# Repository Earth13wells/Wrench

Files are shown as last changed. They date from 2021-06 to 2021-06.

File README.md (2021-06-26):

# Wrench

Print in place, 3D printable ratchet wrench!    

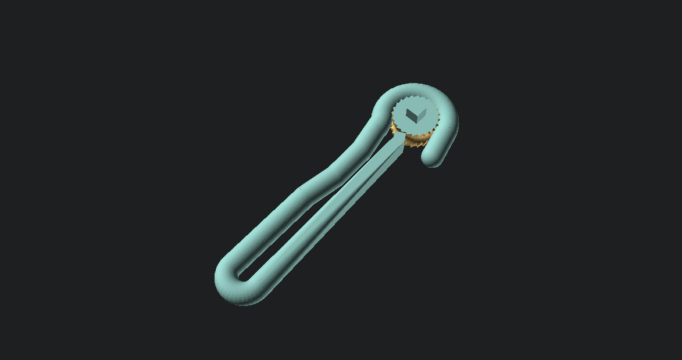
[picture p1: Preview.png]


### Currently Compiling With:
  - OpenScad

### Specs:
  - 1/4" (0.635cm) Drive
  - 3.9" (10 cm) Handle
  - 24 tooth ratchet

### Reasoning:
  - Inspired by the Nasa Space wrench
  - Was a good reason to play with tolerances in openscad

### Suggested Print Settings: (tested V2)
  - Wrench.stl 15-35% infill with 2 permitter+ (tested at 20%,2p)
  - ratchetPaul.stl 30-100% infill with 3 permitter+ (tested at 35%,4p)

## Testing V1:
Using the testing method pictured:         
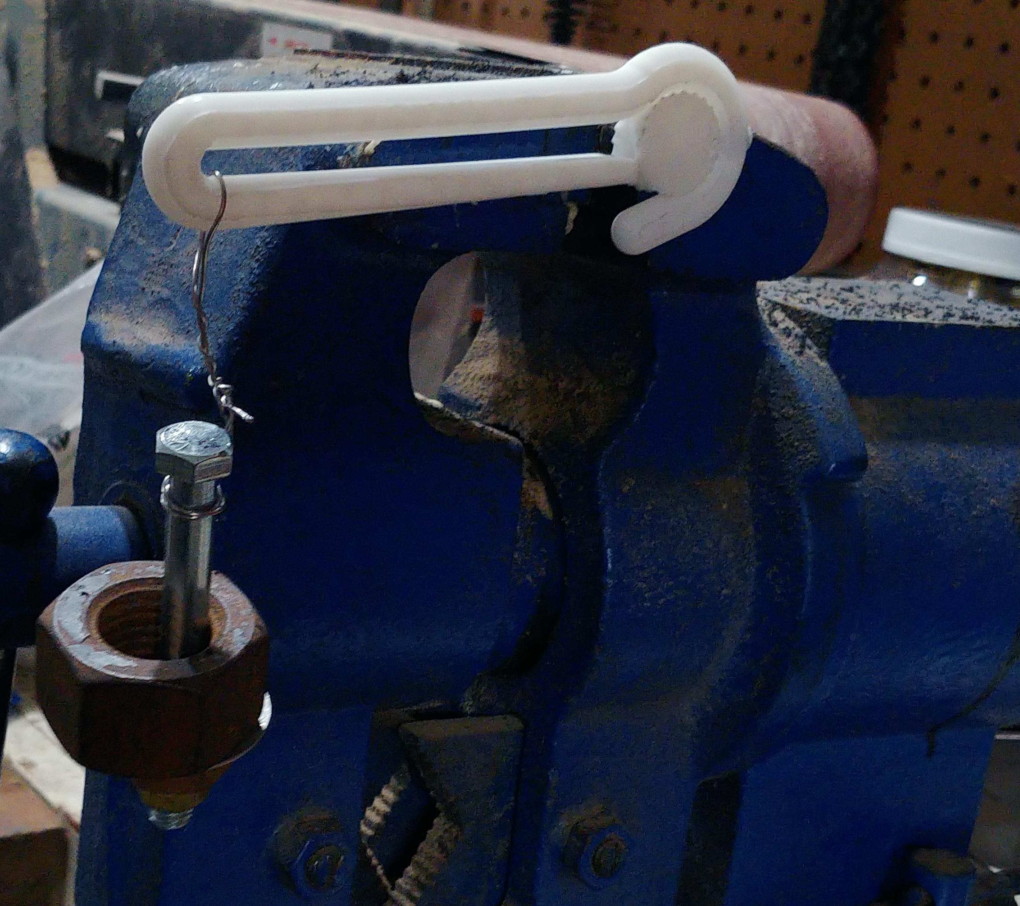
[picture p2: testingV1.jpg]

(weights shown not accurate to final result)         
The wrench was found to support 1.749kg ± .060kg,         
when the mass was suspended 105mm ± 1mm from the centre of the 1/4" drive.         
Using the formula ma/l = τ the force required to break the wrench is:         
```bash
(1.749kg * 9.801N/kg)
 (105mm * 0.001mm/m)   = 1.80N/m (τ)
```
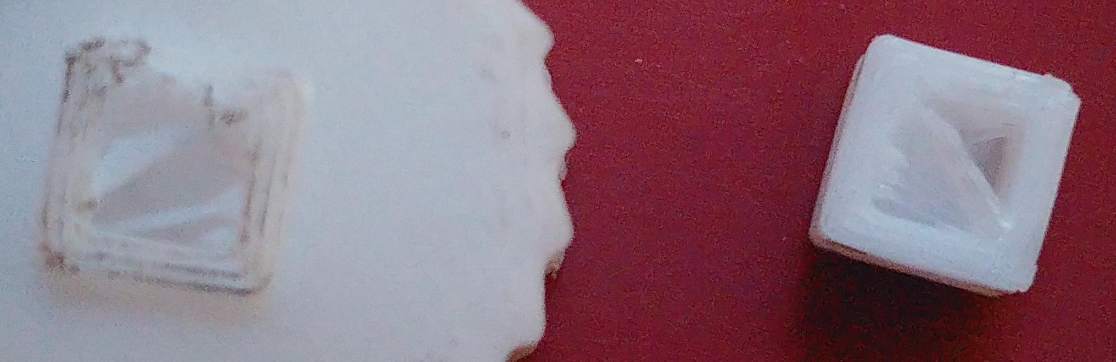
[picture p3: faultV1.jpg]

the fault shown is exactly what was expected, yet not corrected in the design.         
the solution going forward is to print the handle and ratchet separately,         
as the infill/permitter count can be increased on the weaker parts         
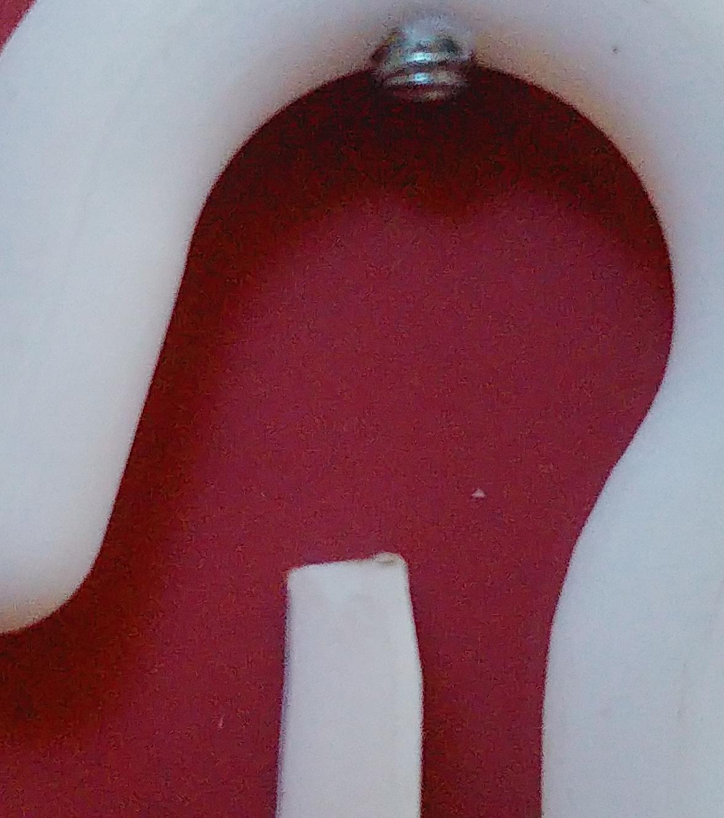
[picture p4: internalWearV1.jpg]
         
The lack of wear on the internals is a very welcome sight, as this part will not need to be redesigned.         
The lever arm is also in excellent condition         
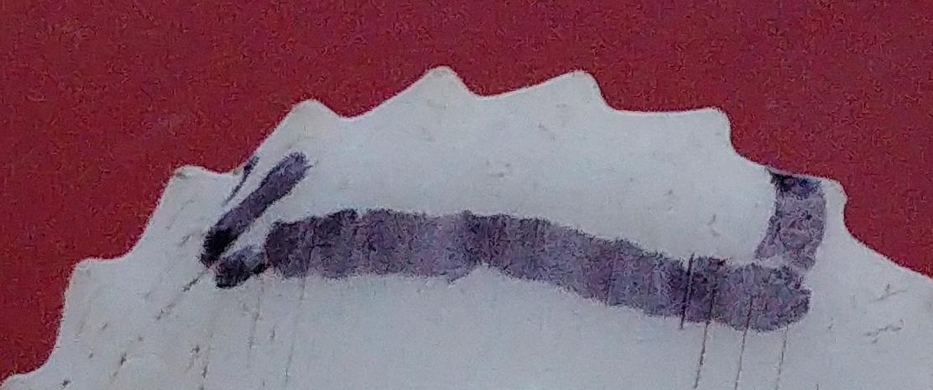
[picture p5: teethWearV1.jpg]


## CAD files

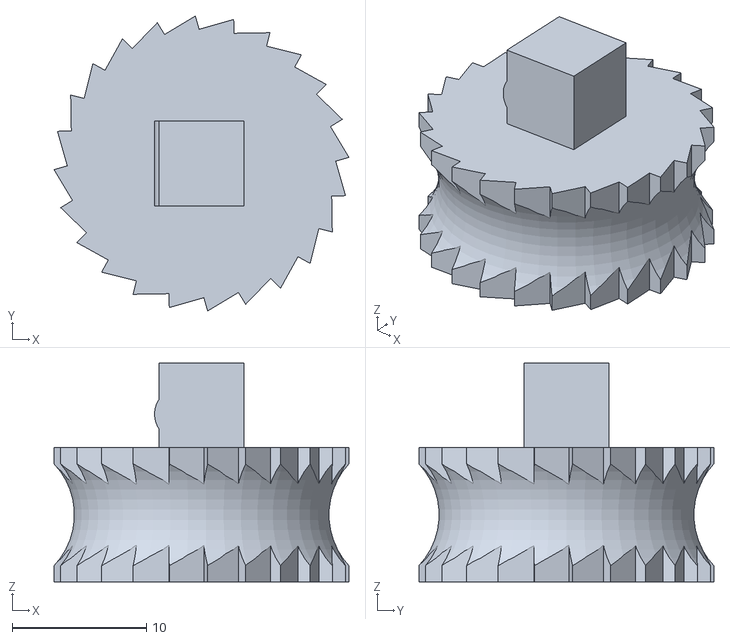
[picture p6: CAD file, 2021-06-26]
ratchetPaul.stl
22.0 x 22.0 x 16.3

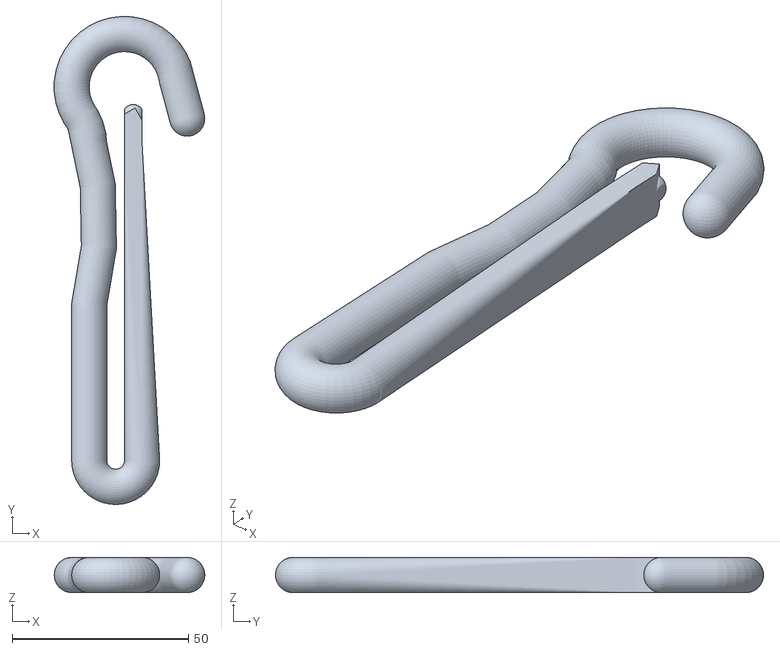
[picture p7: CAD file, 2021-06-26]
Wrench.stl
42.7 x 138.5 x 10.0

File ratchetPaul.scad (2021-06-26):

$fn = 45;
difference(){
	cylinder(r=12,h=10);
	translate([0,0,5]){
			rotate([0,0,20]){
				rotate_extrude(angle=360){
					translate([15,0,5])circle(r=5.5);
				}
			}
		}
	translate([0,0,5]){
		for ( i = [1:15:360]){
			rotate([0,0,i]){
				translate([0,10,-5.5]){
					rotate([0,0,15]){
						color([1,0,0])cube([10,10,11]);
					}
				}
			}
		}
	}
}
translate([-6.3/2,-6.3/2,10]){
	cube([6.3,6.3,6.3]);
}
translate([-1.5,6.3/2,12.5]){
	rotate([90,0,0]){
		cylinder(r=2, h=6.3);
	}
}

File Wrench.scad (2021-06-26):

$fn = 40;
x=-1; //adjust the depth of paul
difference(){
	union(){
		translate([0,0,5]){
			rotate([0,0,20]){
				rotate_extrude(angle=180+12){
					translate([15,0,5])circle(r=5);
				}
			}
		}
		color([0,0,1])
		translate([-25,-20+3.5,5]){
			rotate([180,0,40]){
				rotate_extrude(angle=40){
					translate([15,0,5])circle(r=5);
				}
			}
		}
		translate([-10,-61.4,5]){
			rotate([90,0,0]){
				cylinder(r=5, h=44.6);
			}
		}
		translate([13.8,6,5]){
			hull(){
				rotate([90,0,15]){
					color([0,1,0])cylinder(r=5, h=15);
				}
				translate([4,-15,0])sphere(r=5);
			}
		}
		translate([-101,-38.5,5]){
			difference(){
				rotate([0,0,17]){
					rotate_extrude(angle = -31.9){
						translate([94,0,0])circle(r=5);
					}
				}
			}
		}
		translate([5,-16,5]){
			color([0,1,1]){
				hull(){
					translate([0,-90,0]){
						rotate([90,0,0]){
							cylinder(r=5, h=1);
						}
					}
					translate([-5,-x-6,-5])cube([5,5,10]);
				}
			}
		}
		translate([-2.5,-106,5]){
			rotate_extrude(angle=-180){
				translate([7.5,0,0])circle(r=5);
			}
		}
		
	}
	difference(){
		color([1,0,0])cylinder(r=15,h=10);
		translate([0,0,5]){
			rotate_extrude(angle=360){
				translate([15,0,5])circle(r=5);
			}
		}
	}
}
difference(){
	union(){
		translate([3,-8+1-x,0])rotate([0,0,180+30])cube([20,10,10]);
		translate([2.5,-10+1-x,5])rotate([0,90,0])sphere(r=3);
	}
	translate([5,-50,0])cube([100,100,100]);
	translate([-100,-50,0])cube([100,100,100]);

}

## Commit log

2021-06-19 Added Wrench.scad Added README.md Added Wrench.stl Added Preview.png
    [Wrench.scad, Wrench.stl]
2021-06-26 Split Stl into paul and wrench
    [Wrench.scad, Wrench.stl, ratchetPaul.scad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]
